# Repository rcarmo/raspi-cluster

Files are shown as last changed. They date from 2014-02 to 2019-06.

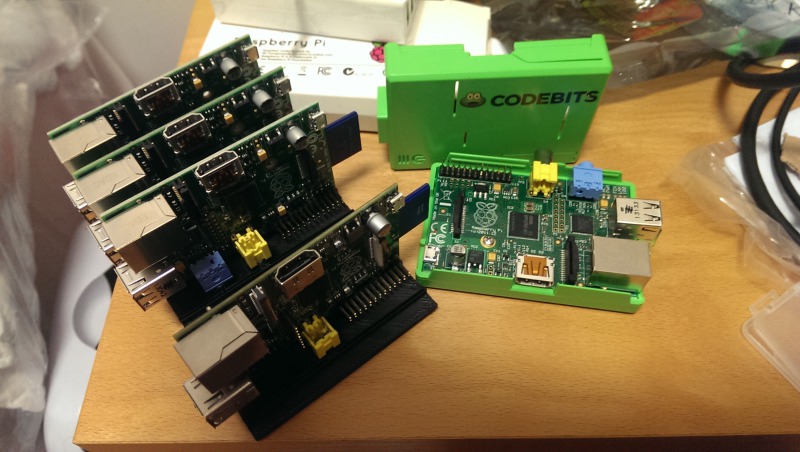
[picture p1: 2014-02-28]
pics/first_assembly.jpg

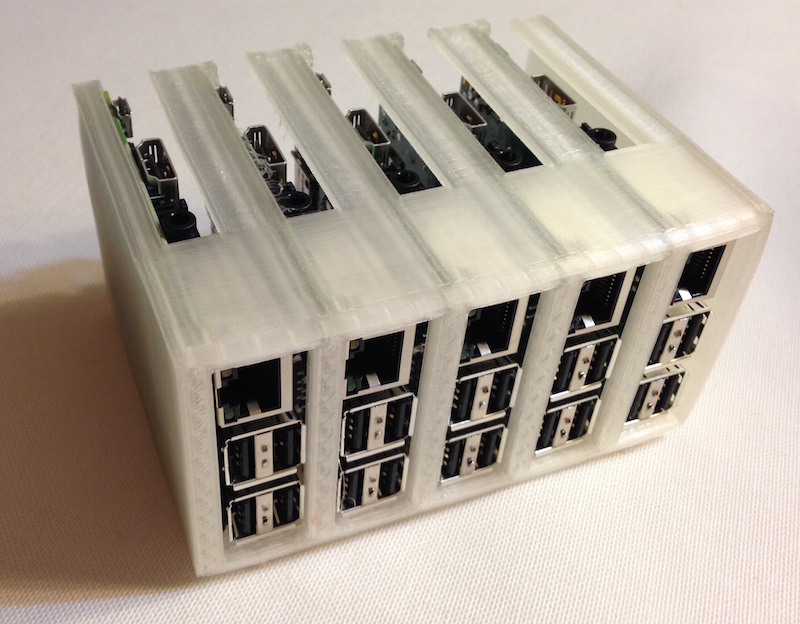
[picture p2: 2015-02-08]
pics/pi2.jpg

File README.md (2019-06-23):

# raspi-cluster (now with Kubernetes thanks to k3s!)

Pi 2

## What?

A while ago I decided to build a small cluster of [Raspberry Pi][rpi] boards. I've since upgraded to Pi 2 boards, and this repository is used for versioning design notes, configuration files and sundry.

## Why?

I wanted something challenging to do in terms of distributed processing, and lacked dedicated hardware to do it. There's a lot to be learned even from simple, unsophisticated solutions, and virtual machines can only do so much.

## How?

The cluster consists of five nodes: a master and four slaves. The master acts as a gateway, DHCP and NFS server and the slave nodes get their IP address and `/srv/jobs` directory from it.

All slave nodes are identical -- _completely_ identical, except for hostname and MAC address, and there is no need to log in and configure things manually for each node.

Here's a few more shots of the original version, with the 5-port PSU and the old Model B boards:

Cabled
Power cords
First assembly

In retrospect I probably ought to have gone for longer USB cables and moved all of the cabling to the USB side (since it leaves the SD card slot clear), but I also need to be able to see the activity lights, and the Pi isn't exactly designed for easy stacking.

A larger cluster is certainly feasible, but 5 boards is as much as I can power with the PSU I have.

## Hardware

This is a partial list of the stuff I'm using (Amazon UK affiliate links):

* 5x Raspberry Pi 2 Model B, which replaced the [Raspberry Pi Model B](http://www.amazon.co.uk/Raspberry-Pi-Model-512MB-RAM/dp/B008PT4GGC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) boards (duh!)
* [7x Class 10 Micro SD Cards](http://www.amazon.co.uk/gp/product/B0036V5DGG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) (2 master cards, 5 for production), which replaced the [Class 10 SD Cards](http://www.amazon.co.uk/gp/product/B003VNKNEG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)
* [1x TP-Link 5-port Ethernet switch](http://www.amazon.co.uk/TP-Link-TL-SF1005D-100Mbps-Unmanaged-Desktop/dp/B000FNFSPY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) and some ancient cables I had lying around (need to build new stripped down ones)
* [5x 6 inch micro USB cables](http://www.amazon.co.uk/gp/product/B003YKX6WM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)
* [1x 5 port USB PSU](http://www.amazon.co.uk/gp/product/B00EKDVGKQ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)
* 1x ancient Bondi Blue iMac USB keyboard.
* 1x Custom-printed rack case (see SCAD files in the `3d_models` folder)

## Software

As a base OS, this cluster spent most of its useful life using [the Ubuntu 16.04 official image for the Pi 2][ub], which worked much better than Raspbian for running Swarm, Docker or Spark (nevertheless, the configuration files in this repo should work in both systems).

Up to the point where I had unfettered access to public cloud resources as part of my work, the cluster ran a mix of Docker Swarm and the occasional [Clojure][clj] program using [Hazelcast][hz] atop JDK 1.8, as well as [Jupyter][jy], which runs very nicely indeed and provided me with an agnostic, notebook-oriented front-end.

Earlier (back in the Rev 1 days) I had set up [Disco][dp] on it and intended to fiddle with MPI, but now I have plenty more ways to parallelize things.

It's a bit ironic to do some kinds of processing on merely 5GB of aggregated RAM, but my interest was in the algorithms themselves and I never planned on doing something silly like tackling the next Netflix Prize with this -- besides, running things on low-end hardware is often the only way to do proper optimization, and I like the extra challenges.

### List of packages involved so far:

* [k3s][k3s], which is the latest addition and has rendered pretty much everything else below obsolete. See the `k3s` folder for a simple `Makefile` to install it and keep it running.
* [etcd][etcd], which I was using to store (and distribute) configurations across nodes
* [Docker][do], which ships with Ubuntu 14.04 and makes it a lot easier to build and tear down environments. Currently trying to get 1.7 to build so I can use `swarm` and other niceties.
* [OpenVSwitch][ovs], which I'm using for playing around with network topologies
* [Jupyter][jy], which provides me with a nice web front-end and basic Python parallel computing.
* [Spark][spark], which has mostly replaced [Disco][dp] for map/reduce jobs.
* [Dash](https://github.com/rcarmo/dash), a real-time status dashboard (rewritten in [Go][golang], available under the `dashboard` folder here, and still being worked on)
* A custom daemon that sends out a JSON-formatted multicast packet with system load, CPU usage and RAM statistics (written in raw C, available in `tools`)
* [ElasticSearch](http://www.elasticsearch.org), which I'm using for storing metrics.
* Oracle [JDK 8](https://jdk8.java.net/download.html)
* [leiningen][lein] (which fetches [Hazelcast][hz] and other dependencies for me, via [this library][clj-hz])
* [Nightcode][nc] as a development environment ([LightTable][lt] doesn't run on ARM, and a lot of my hobby coding these days is actually done on an [ODROID][u2])
* `distcc` for building binaries slightly faster
* `dnsmasq` for DHCP and DNS service

This repository also ships with a very simple monitoring dashboard that looks like this:

Updated dashboard

## But isn't the [Raspberry Pi][rpi] slow?

Well spotted, young person. It was, and the Pi 2, despite being a marked improvement, isn't exactly a supercomputer. But it's also cheap, and beggars can't be choosers.

Nevertheless, the current configuration provides me with 20 ARMv7 cores clocked at 1GHz, and that's nothing to sneeze at.

But I'm open to [sponsoring][d] so that I can upgrade this to have at least twice as many boards, or move to a set of beefier ARM64 boards. The [NVIDIA Jetson](https://developer.nvidia.com/buy-jetson), in particular, would be great, but five of them aren't easy to come by.

[etcd]: https://github.com/coreos/etcd
[hz]: http://www.hazelcast.org
[rpi]: http://www.raspberrypi.org
[d]: http://the.taoofmac.com/space/site/Donate
[u2]: http://hardkernel.com/main/products/prdt_info.php?g_code=G135341370451
[u3]: http://hardkernel.com/main/products/prdt_info.php?g_code=G138733896281
[clj]: http://www.clojure.org
[hz]: http://www.hazlecast.org
[nc]: https://github.com/oakes/Nightcode
[lt]: http://lighttable.com
[moebius]: http://moebiuslinux.sourceforge.net
[lein]: http://leiningen.org
[clj-hz]: https://github.com/rcarmo/clj-hazelcast
[dp]: http://discoproject.org
[golang]: http://www.golang.org
[spark]: http://spark.apache.org
[jy]: http://jupyter.org
[ub]: https://wiki.ubuntu.com/ARM/RaspberryPi
[do]: http://docker.io
[ovs]: http://openvswitch.org/
[k3s]: http://k3s.io

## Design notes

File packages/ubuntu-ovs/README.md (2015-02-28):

These are [OpenVSwitch][ovs] packages for Ubuntu 14.04 on the Raspberry Pi 2, compiled from the 2.3.1 tarball.

Although they seem to work, they are highly experimental. Use with caution.

[ovs]: http://openvswitch.org/

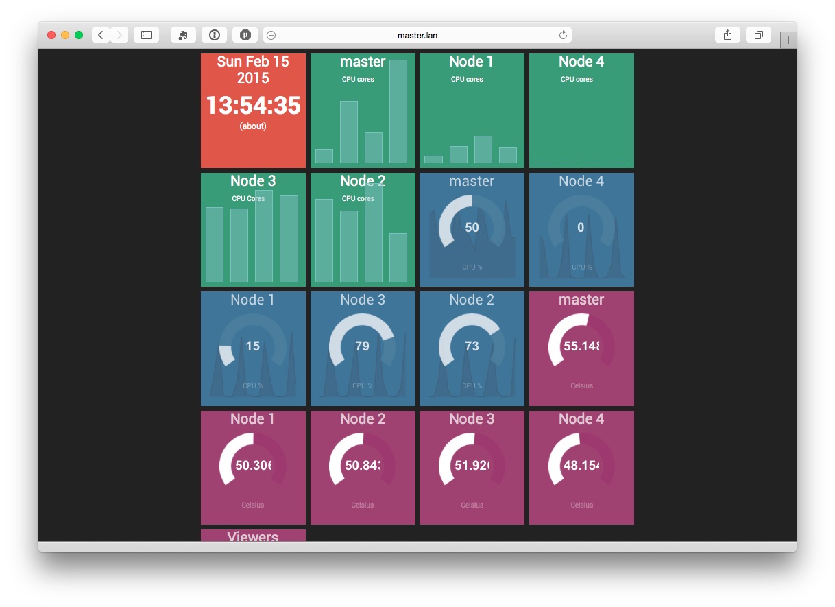
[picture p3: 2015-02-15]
pics/dash.jpg

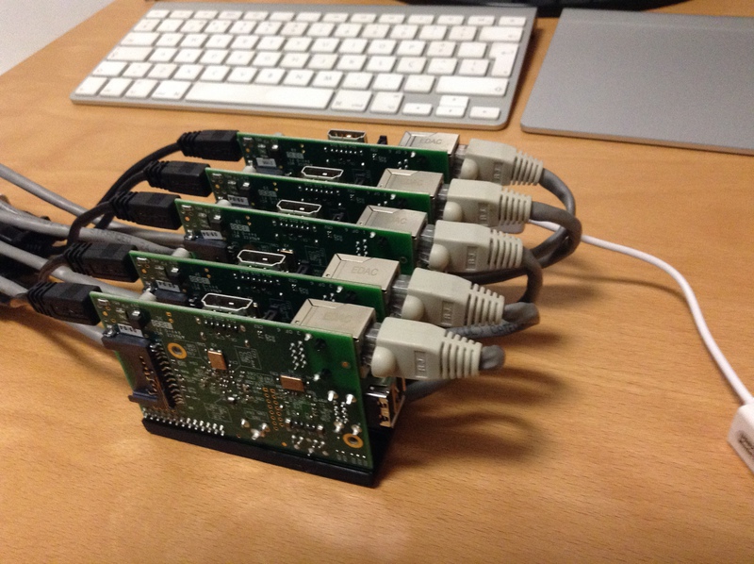
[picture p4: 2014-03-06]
pics/ethernet.jpg

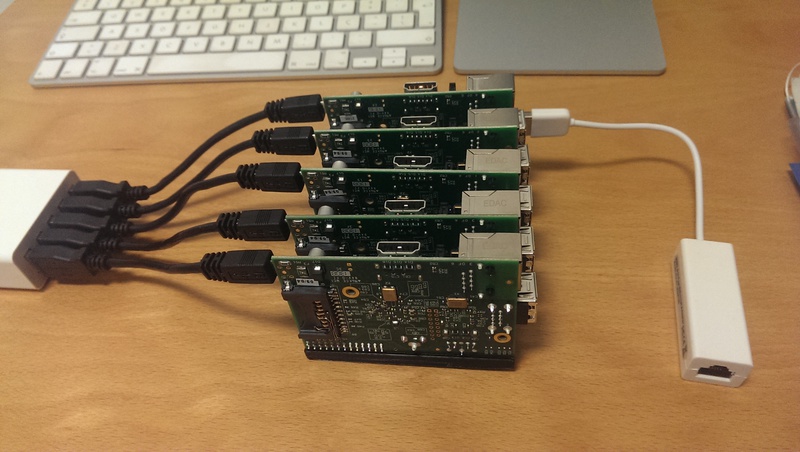
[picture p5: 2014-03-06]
pics/micro_usb.jpg

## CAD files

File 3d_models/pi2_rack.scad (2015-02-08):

//preview[view:east, tilt:top]

/* A remix of http://www.thingiverse.com/thing:664343 designed to:
   - put boards upright and hold them in place
   - provide minimal convection airflow
   - provide some headroom to prevent bumping the Micro SD card */

/* [Global] */
//how many raspis to stack on each other
rack_height=5; //[1:10]


/* [Hidden] */
rpi_width=57.5;
rpi_length=87;
u_height=23;
wall=2;
ledge=2;
port_height=11;
port_len=61;

module rack_side(){
    translate([0,-3*wall,-wall])
        cube([rpi_width+2*wall,rpi_length+wall*4,wall]);
}

module one_u(){
    difference(){
        translate([0,-wall*3,0])
            cube([rpi_width+2*wall,rpi_length+wall*4,u_height]);

        // cut out main area
        translate([wall,-wall*5,wall])
            cube([rpi_width,rpi_length+wall*4,u_height]);
        //cut floor
        translate([wall+ledge,-wall*4,-wall])
            cube([rpi_width-2*ledge,rpi_length+wall*3,3*wall]);
        //back
        translate([wall+1,rpi_length-2*wall,ledge+1])
            cube([rpi_width-2,5*wall,u_height-1-2*wall]);
        //top ports
        translate([rpi_width,-wall*4,wall])
            cube([5*wall,port_len+wall*4,port_height]);
        //power plug clearance
        translate([rpi_width-wall,wall*3,-wall])
            cube([4*wall,wall*7,port_height-wall*2]);
        //bottom ports
        translate([-wall,wall*2,wall*3])
            cube([3*wall,port_len-wall*3,port_height]);
        // remove leading edge of rails
        translate([wall,-wall*4,-wall])
            cube([rpi_width,wall*2,u_height]);
    }
}

module board_clips(index) {
    translate([0,wall,wall*1.2])
        difference(){
            union() {
                cube([2*wall,2*wall,2*wall]);
                if(index>1) {/* remove top clip so board will slide in */
                    translate([rpi_width,0,-wall])
                        cube([2*wall,2*wall,3*wall]);
                	    // breakaway support
	                translate([rpi_width+wall,wall*2-0.4,-wall*2])
    		                cube([wall,0.4,u_height]);
                }
                translate([0,rpi_length-wall*3,0])
                    cube([2*wall,2*wall,2*wall]);
                translate([rpi_width,rpi_length-wall*3,0])
                    cube([2*wall,2*wall,2*wall]);
            }
            translate([0,-wall,-0.4])
                cube([rpi_width+wall,rpi_length+2*wall,wall*1.2]);
        }
}

module raspi_rack(){
    rack_side();
    for(i=[1:rack_height]){
        translate([0,0,(i-1)*u_height])
            one_u();
        translate([0,0,(i-1)*u_height])
            board_clips(i);
    }
    // mirror side
    translate([0,0,rack_height*u_height])
        rack_side();
    // feet
    translate([-wall*2,wall,u_height/2+wall*4])
        cube([3*wall,4*wall,4*wall]);
    translate([-wall*2,rpi_length-4*wall,wall*2])
        cube([3*wall,4*wall,4*wall]);
    translate([0,0,rack_height*u_height-wall*13]){
        translate([-wall*2,wall,-wall])
            cube([3*wall,4*wall,4*wall]);
        translate([-wall*2,rpi_length-4*wall,u_height/2])
            cube([3*wall,4*wall,4*wall]);
    }
    // adhesion pads to prevent warping
    translate([-wall*4,rpi_length+wall-0.2,-wall*5])
        cube([10,0.2,10]);
    translate([rpi_width+wall,rpi_length+wall-0.2,-wall*5])
        cube([10,0.2,10]);
	translate([0,0,rack_height*u_height+wall*4]) {
    		translate([-wall*4,rpi_length+wall-0.2,-wall*5])
            cube([10,0.2,10]);
    		translate([rpi_width+wall,rpi_length+wall-0.2,-wall*5])
            cube([10,0.2,10]);
    }
    
}

//rotate & center
translate([(rack_height*u_height)/2,-(rpi_width+2*wall)/2,rpi_length+wall])
    rotate([-90,0,90])
        raspi_rack();

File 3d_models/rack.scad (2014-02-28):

/*
 * A mounting platform for a "rack" of 5 Raspberry Pi boards
 */

rca_pos = [46.5,11,0];
audio_pos = [65,10,0];

// Used to build dovetails, if you want
snap1_pos = [5,-3,0];
snap2_pos = [70,-3,0];

module base() {
    // carve out a base cube to provide two support ridges:
    // one for the board and another place to hold an expansion board

	difference(){
  		difference(){
  			cube([85.6,25.0,7]);
			translate([0,2,3])
				cube([90,14,5]);
		}
		translate([0,18,3])
			cube([90,12,5]);
	}
}

module load_bearing() {
    // these will surround the RCA and audio jacks and provide some rigidity

	union() {
		base();
		translate(rca_pos)
			cylinder(h = 7, r = 5.5, center = false
);
		translate(rca_pos - [1,10,0])
			cube([2,16,7], center = false);

		translate(audio_pos)
			cylinder(h = 7, r = 4.5, center = false);

		translate(audio_pos - [1,9,0])
			cube([2,13,7], center = false);

		translate(audio_pos + [-1,2,0])
			cube([2,5,7], center = false);
	}
}


module holes() {
    // punch out all the holes at once

	union() {
		translate(rca_pos)
			cylinder(h = 9, r = 4.4, center = false);
		translate(audio_pos)
			cylinder(h = 9, r = 3.6, center = false);
	}

    // not going to use the dovetails
/*
	translate([0,22,0])
		union() {
			translate(snap1_pos)
				scale([1.1,1.1,1])
					triangle();
			translate(snap2_pos)
				scale([1.1,1.1,1])
					triangle();
		}
*/
}


module triangle (side=10, height=3, center=false) {
    // base triangle for dovetails

	translate(center==true ? [-side/2,-sqrt(3)*side/6,-height/2] : [0,0,0])	
		linear_extrude(height=height)
			polygon(points=[[0,0],[side,0],[side/2,sqrt(3)*side/2]]);
}


module dovetails() {
	union() {
		translate(snap1_pos)
			triangle();
		translate(snap2_pos)
			triangle();
	}
}

module single(){
union() {
   // dovetails();
	difference() {
		load_bearing();
		holes();
	}
}
}

// make 5 in a row
for(y = [0,25,50,75,100]) {
	translate([0,y,0])
		single();
}

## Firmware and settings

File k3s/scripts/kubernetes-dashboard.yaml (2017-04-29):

# Copyright 2015 Google Inc. All Rights Reserved.
#
# Licensed under the Apache License, Version 2.0 (the "License");
# you may not use this file except in compliance with the License.
# You may obtain a copy of the License at
#
#     http://www.apache.org/licenses/LICENSE-2.0
#
# Unless required by applicable law or agreed to in writing, software
# distributed under the License is distributed on an "AS IS" BASIS,
# WITHOUT WARRANTIES OR CONDITIONS OF ANY KIND, either express or implied.
# See the License for the specific language governing permissions and
# limitations under the License.

# Configuration to deploy release version of the Dashboard UI compatible with
# Kubernetes 1.6 (RBAC enabled).
#
# Example usage: kubectl create -f <this_file>

apiVersion: v1
kind: ServiceAccount
metadata:
  labels:
    app: kubernetes-dashboard
  name: kubernetes-dashboard
  namespace: kube-system
---
apiVersion: rbac.authorization.k8s.io/v1beta1
kind: ClusterRoleBinding
metadata:
  name: kubernetes-dashboard
  labels:
    app: kubernetes-dashboard
roleRef:
  apiGroup: rbac.authorization.k8s.io
  kind: ClusterRole
  name: cluster-admin
subjects:
- kind: ServiceAccount
  name: kubernetes-dashboard
  namespace: kube-system
---
kind: Deployment
apiVersion: extensions/v1beta1
metadata:
  labels:
    app: kubernetes-dashboard
  name: kubernetes-dashboard
  namespace: kube-system
spec:
  replicas: 1
  revisionHistoryLimit: 10
  selector:
    matchLabels:
      app: kubernetes-dashboard
  template:
    metadata:
      labels:
        app: kubernetes-dashboard
    spec:
      containers:
      - name: kubernetes-dashboard
        image: gcr.io/google_containers/kubernetes-dashboard-arm:v1.6.0
        imagePullPolicy: Always
        ports:
        - containerPort: 9090
          protocol: TCP
        args:
          # Uncomment the following line to manually specify Kubernetes API server Host
          # If not specified, Dashboard will attempt to auto discover the API server and connect
          # to it. Uncomment only if the default does not work.
          # - --apiserver-host=http://my-address:port
        livenessProbe:
          httpGet:
            path: /
            port: 9090
          initialDelaySeconds: 30
          timeoutSeconds: 30
      serviceAccountName: kubernetes-dashboard
      # Comment the following tolerations if Dashboard must not be deployed on master
      tolerations:
      - key: node-role.kubernetes.io/master
        effect: NoSchedule
---
kind: Service
apiVersion: v1
metadata:
  labels:
    app: kubernetes-dashboard
  name: kubernetes-dashboard
  namespace: kube-system
spec:
  type: NodePort
  ports:
  - port: 80
    targetPort: 9090
  selector:
    app: kubernetes-dashboard

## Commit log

2014-02-28 README and STL
    [rack.scad]
2014-05-02 Working cpu temperature chart
2015-02-08 SCAD file for Pi 2 rack
    [pi2_rack.scad]
2015-02-08 various improvements to rack dimensions
    [pi2_rack.scad]
2015-02-08 breakaway supports and power clearance
    [pi2_rack.scad]
2015-02-08 Update pi2_rack.scad
    More tweaks to power plug location.
    [pi2_rack.scad]
2015-02-08 tiny fix to breakaway support
    [pi2_rack.scad]
2015-02-15 favicon, tired of spurious 404s
2016-08-11 Create mathematica.yml
    Ansible script for deploying Mathematica on Ubuntu ARM
2017-05-28 quick and dirty LED status, updated Spark
